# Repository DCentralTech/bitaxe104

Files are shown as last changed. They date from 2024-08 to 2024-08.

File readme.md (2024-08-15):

# The bitaxe
bitaxe is the first fully open source hardware Bitcoin ASIC miner.
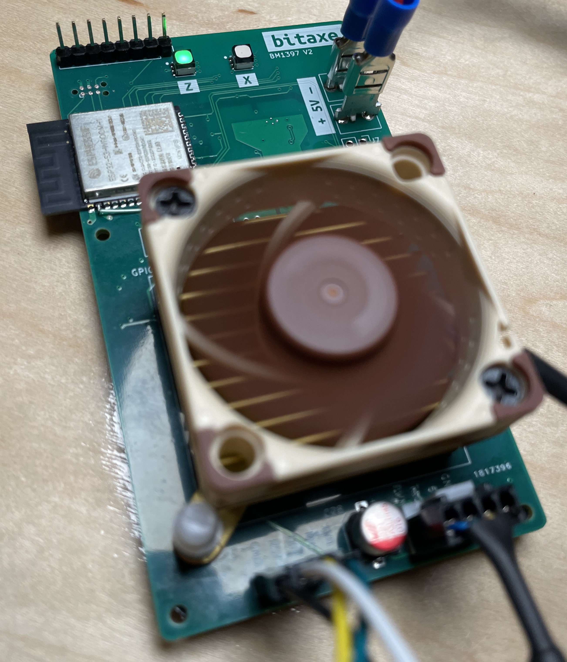
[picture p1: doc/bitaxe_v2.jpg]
bitaxeMax assembled


## Goals
- **Standalone**: can mine directly to your pool over WiFi. No External computer needed.
- **Embedded**: low cost, low maintenance, high availability, high reliability, low power.
- **ASIC**: based on the very efficient BM1397 from Bitmain.
- **Versatile**: solo/pool mining, autotune power/heat/efficiency.
- **Open Source**: All design files are provided.

## Features
- **ESP32-S3-WROOM-1** wifi microcontroller on board
- **TI TPS40305** buck regulator steps down the 5V input to power the BM1397
- **Maxim DS4432U+** current DAC digitally adjusts the BM1397 core voltage from 0.04V to 2.4V
- **TI INA260** power meter measures the input voltage and current of the miner
- **Microchip EMC2101** measures the BM1397 internal diode temperature. Also PWM controls the fan and monitors tach output.
- Two **sweet** RGB status LEDs

## BM1397
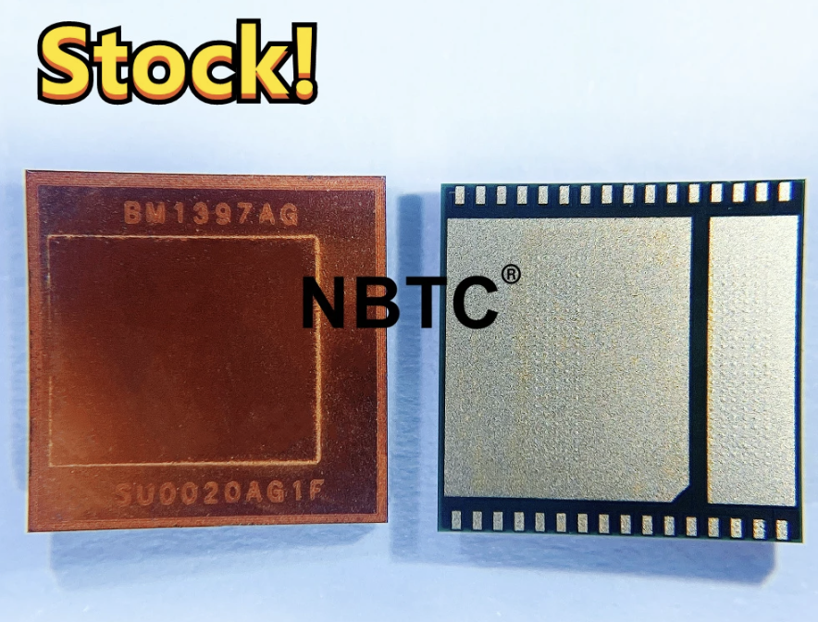
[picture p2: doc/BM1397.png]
BM1397 pic


- The BM1397 is a undocumented SHA256 mining ASIC from Bitmain. It's mostly used in the Antminer S17 and T17
- Bitmain claims the BM1397 has 0.03J/GH efficiency
- The BM1397 is available (new) for around $20 each and (used) for around $6 ea in small quantities.
- Choose your BM1397 version: [Guide here](https://d-central.tech/bm1397-ad-ag-ah-ai-antminer-17-series-chip-replacement-guide/)
- The BM1397 has the same footprint as the BM1387, but a very different pinout.
    - It also has two "Modes" that change some of the signal pins around to make chaining easy
- The BM1397 is driven by an undocumented protocol over UART. Baudrate is 115200bps by default but can go up to 6Mbps in order to provide mining jobs quickly enough to the ASIC daisy-chain.

## Current Status
- The hardware has been built and tested.
- Using cgminer on a separate computer, the bitaxe can mine in excess of 400 GH/s
- ESP32 miner firmware is still underdevelopment.

## Hardware
- [BM1397 from random AliExpress seller](https://www.aliexpress.com/item/3256802274958527.html). I got the "AG" variant. Not really sure what the difference is.
- [40x40mm heatsink and 5V fan](https://www.aliexpress.com/item/2251832861666365.html) from a random AliExpress seller. At least half of these arrived broken in some way. But they are cheap and the working ones do keep the BM1387's nice and cool when used with some thermal compound.
    - Swap this fan with the [Noctua NF-A4x10](https://noctua.at/en/products/fan/nf-a4x10-pwm) 5V 4-Pin fan for a much more pleasant experience.
- The BM1397 serial port is 1.8V. These pins are broken out, but the main idea is to communicate with the BM1397 from the ESP32
- Level shifters to interface the 1.8V BM1397 with the 3.3V ESP32. These pins are also broken out.
- [KiCad 6](https://www.kicad.org) design files
- All of the parts on the board are listed in the KiCad BOM

## Software
- [ESP-Miner](https://github.com/skot/ESP-Miner) firmware in progress.

## Power Supply Requirements
- [5VDC Power supply](https://www.amazon.com/BTF-LIGHTING-Plastic-Adapter-Transformer-WS2812B/dp/B01D8FM4N4). Should be capable of over 15W
    - Needs to connect with [spade-style connectors](https://www.amazon.com/gp/product/B01G4POUAU)

### ESP32 Programming Requirements
- [ESP-Prog](https://www.digikey.com/en/products/detail/espressif-systems/ESP-PROG/10259352) ESP32 Programmer
- [TC2030-IDC-NL](https://www.tag-connect.com/product/tc2030-idc-nl) Tag Connect Cable
- [TC2030-CLIP](https://www.tag-connect.com/product/tc2030-retaining-clip-board-3-pack)

## Connections
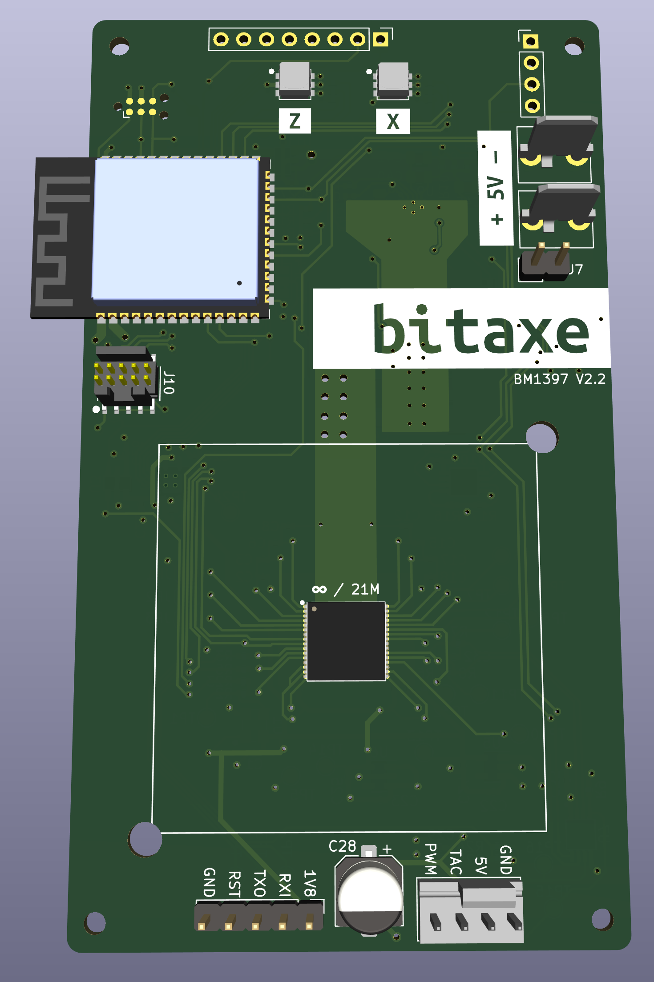
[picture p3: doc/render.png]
bitaxeMax KiCad render


### Power Input
| Pin Name | Description |
| --- | --- |
| +5V | Main input. This should be 5V, 15W |
| GND | Main input ground |

## Building
- Check out [building.md](building.md) for PCB ordering tips
- Check out [assembly.md](assembly.md) for assembly tips

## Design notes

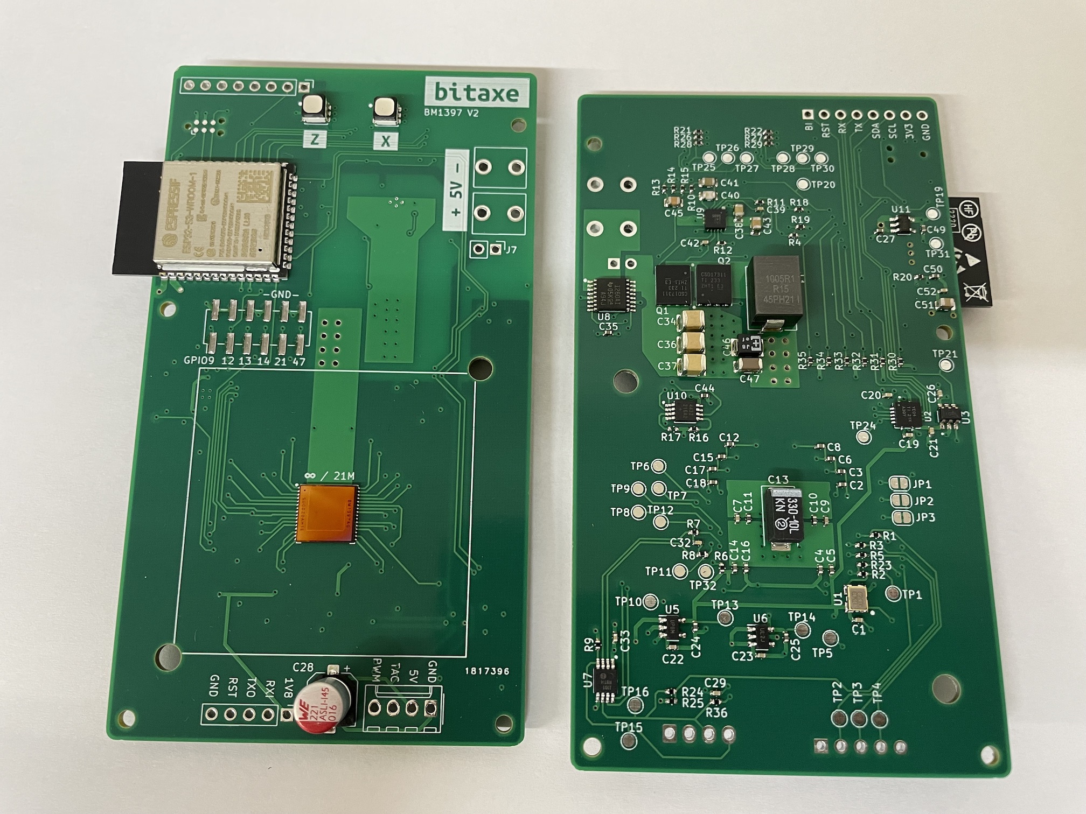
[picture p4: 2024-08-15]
doc/v2_both_sides.jpg

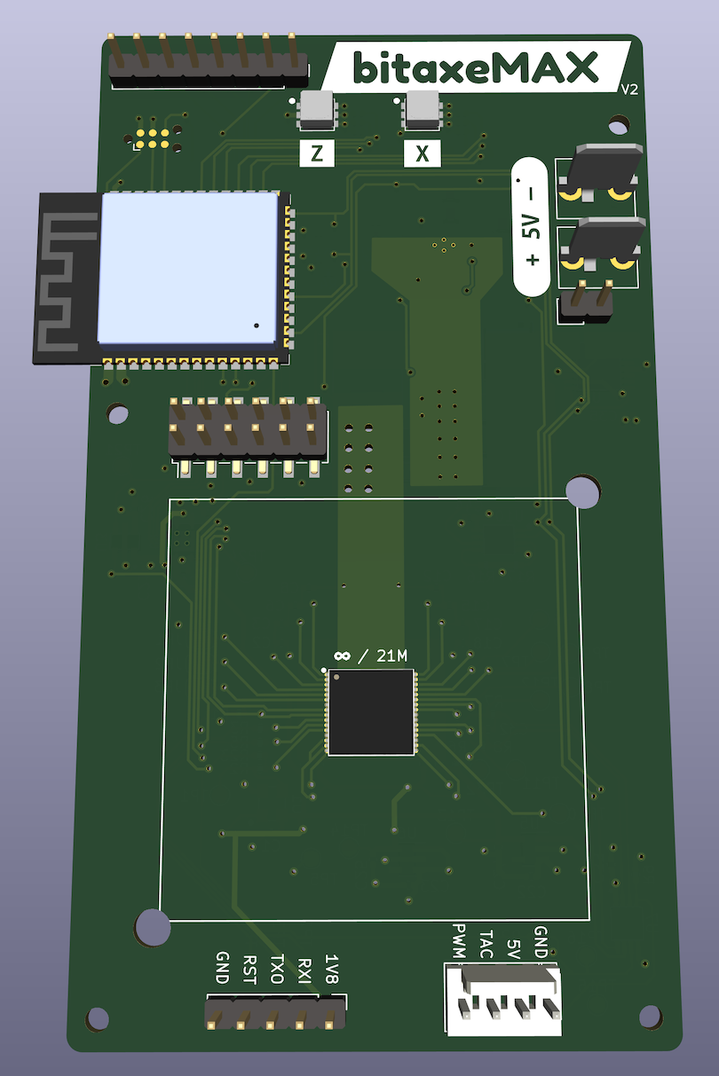
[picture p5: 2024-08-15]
doc/front.png

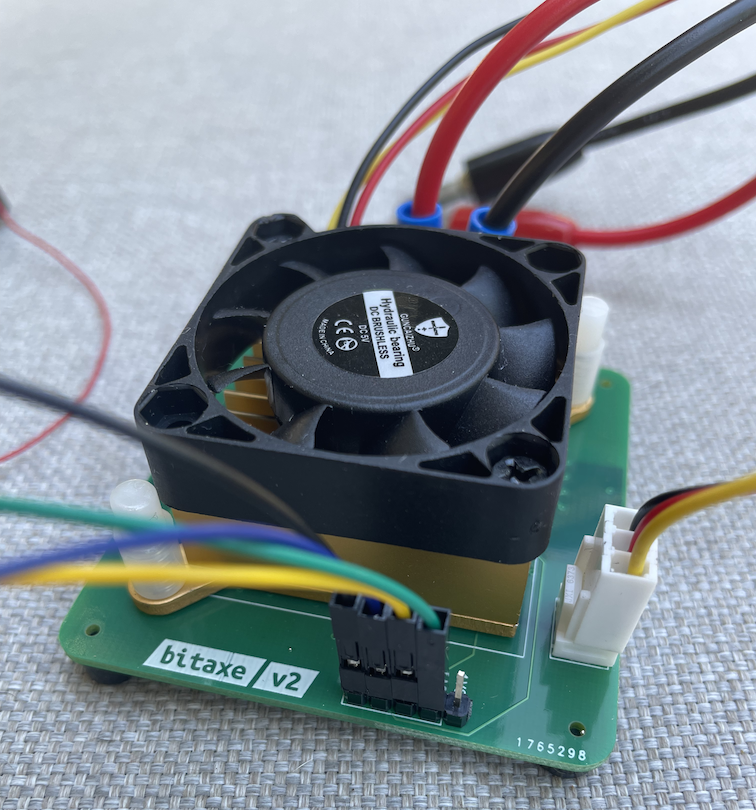
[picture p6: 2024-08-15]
doc/bitaxe.png

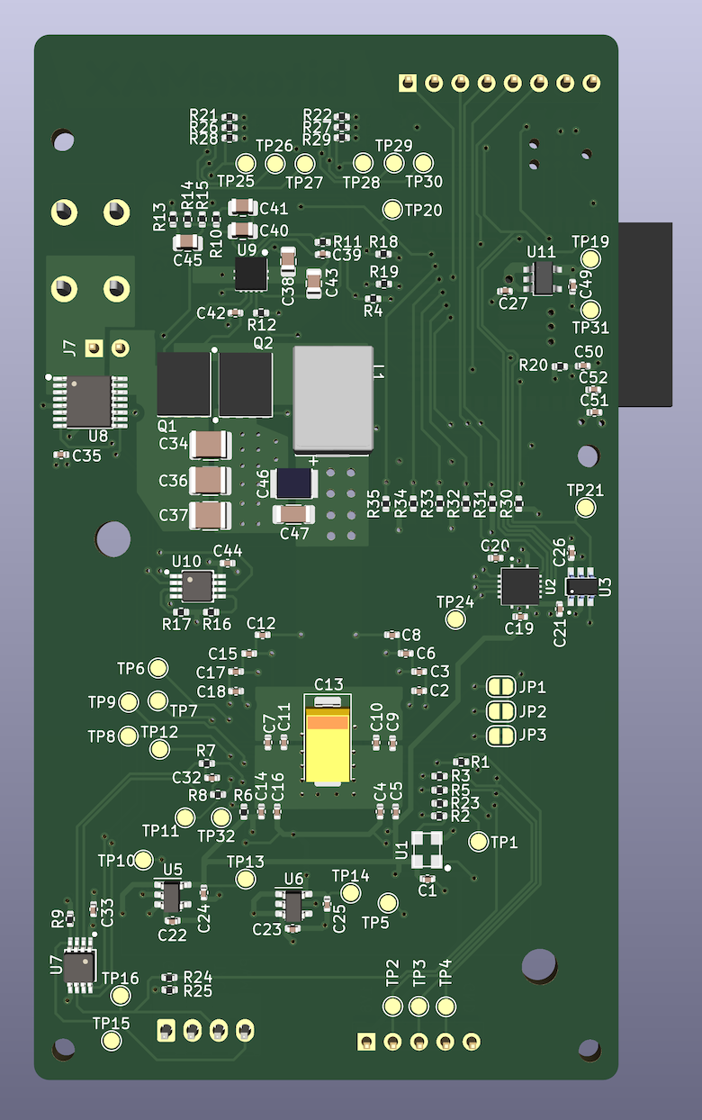
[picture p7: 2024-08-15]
doc/back.png

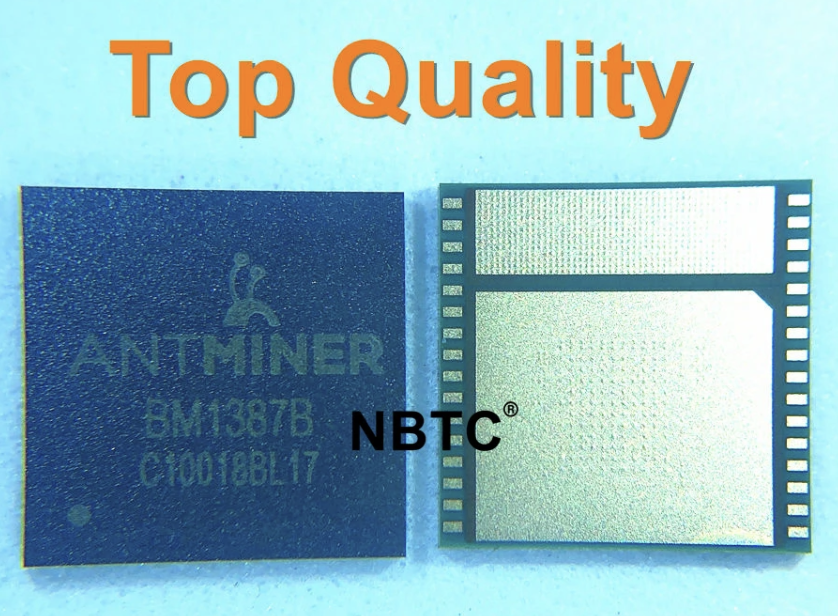
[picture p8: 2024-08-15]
doc/bm1387.png

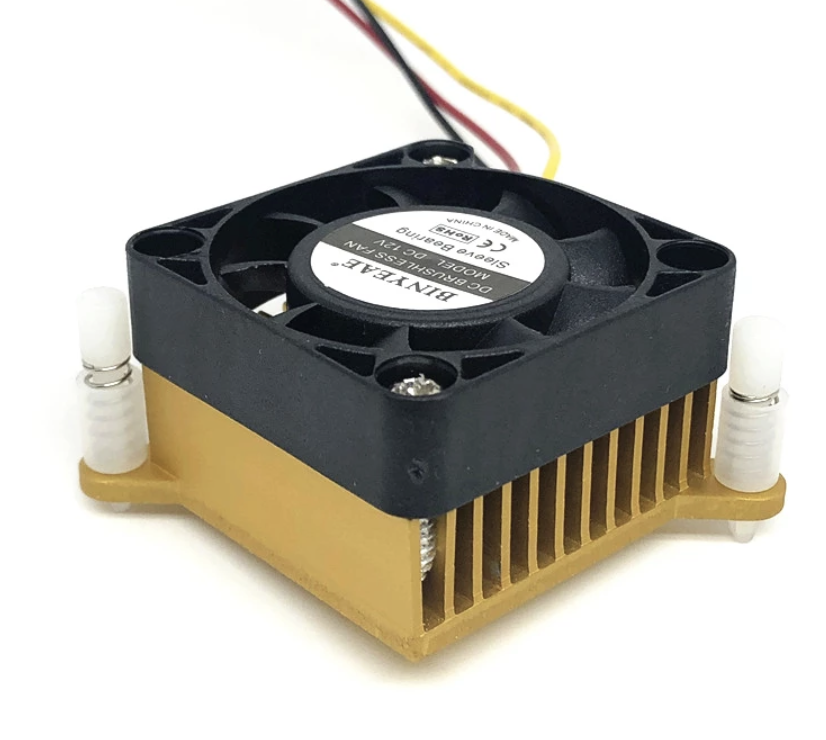
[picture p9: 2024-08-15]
doc/fan.png

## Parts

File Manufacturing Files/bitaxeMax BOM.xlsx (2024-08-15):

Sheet: BOM
Qty | Ref Des | Value | DK | PARTNO | DNP
13 | C1, C7, C9, C19, C20, C21, C22, C23, C26, C29, C33, C42, C52 | 0.1uF | 1292-1639-1-ND
21 | C2, C3, C4, C5, C6, C8, C10, C11, C12, C14, C15, C16, C17, C18, C24, C25, C27, C35, C44, C49, C50 | 1uF | 587-5514-1-ND
1 | C13 | 330uF | 718-1028-1-ND
1 | C28 | 220uF | 732-8422-1-ND | 865080345012
2 | C30, C31 | 6.8pF | 399-C0402C689C5GAC7867CT-ND | C0402C689C5GAC7867
1 | C32 | 470pF | 1276-1566-1-ND
3 | C34, C36, C37 | 47uF | 490-6539-1-ND | GRM32ER61C476KE15L
1 | C38 | 1uF | 1276-6471-1-ND
1 | C39 | 3.3nF | 1276-1552-1-ND
1 | C40 | 180pF | 311-1114-1-ND
1 | C41 | 1.5nF | 311-1128-1-ND
2 | C43, C51 | 10uF | 1276-1096-1-ND
1 | C45 | 470pF | 1292-1580-1-ND
1 | C46 | 220uF | P16200CT-ND | 2R5TPE220MAFB
1 | C47 | 100uF | 445-6008-1-ND | C3216X5R0J107M160AB
4 | H1, H2, H3, H4 | AlignmentHole |  | https://www.amazon.com/dp/B07MDFS1YS | T
2 | H5, H6 | MountingHole |  |  | T
1 | IC1 | BM1397_mode1 |  |  | T
2 | J1, J2 | Conn_01x01 | A100886CT-ND | 63862-1
1 | J3 | Conn_01x05 |  |  | T
1 | J4 | Conn_01x04 | WM4330-ND | 0470531000
1 | J5 | TC2030-IDC |  |  | T
1 | J6 | Conn_01x08 |  |  | T
1 | J7 | Conn_01x02 |  |  | T
1 | J9 | Conn_01x04 |  |  | T
1 | J10 | FTSH-105-01-F-DV-K | SAM8796-ND
2 | JP1, JP2 | SolderJumper_2_Open |  |  | T
1 | JP3 | SolderJumper_2_Bridged |  |  | T
1 | JP4 | JTAG Source
1 | L1 | 150nH | 513-1568-1-ND | FP1005R1-R15-R
2 | Q1, Q2 | CSD17311Q5 | 296-27625-1-ND | CSD17311Q5
3 | R1, R18, R19 | 1k | YAG2306CT-ND |  | T
4 | R2, R3, R5, R23 | 0 | RMCF0402ZT0R00CT-ND
6 | R4, R6, R9, R20, R24, R36 | 10k | 311-10KJRCT-ND
2 | R7, R8 | 100 | RMCF0402FT100RCT-ND
1 | R10 | 3.83k | 311-3.83KLRCT-ND
1 | R11 | 100k | 311-100KJRCT-ND
1 | R12 | 4.12k | RMCF0402FT4K12CT-ND
1 | R13 | 1.33k | 311-1.33KLRCT-ND
1 | R14 | 4.99k | 311-4.99KLRCT-ND
1 | R15 | 3.32k | 311-3.32KLRCT-ND
1 | R16 | 80k | 311-80.6KLRCT-ND
1 | R17 | DNP |  |  | T
2 | R21, R22 | 60.4 | 311-60.4LRCT-ND
1 | R25 | 19.1k | YAG3027CT-ND
2 | R26, R27 | 100 | RMCF0402FT100RCT-ND
2 | R28, R29 | 261 | YAG3078CT-ND
31 | TP1, TP2, TP3, TP4, TP5, TP6, TP7, TP8, TP9, TP10, TP11, TP12, TP13, TP14, TP15, TP16, TP17, TP18, TP19, TP21, TP22, TP23, TP24, TP25, TP26, TP27, TP28, TP29, TP30, TP31, TP32 | TestPoint |  |  | T
1 | U1 | 25MHz | 1908-O250-JO32-B-1V3-1-T1-LFCT-ND | O 25,0-JO32-B-1V3-1-T1-LF
1 | U2 | TXB0104RGYR | 296-21930-1-ND | TXB0104RGYR
1 | U3 | SN74AXC1T45DBVR | 296-47598-1-ND | SN74AXC1T45DBVR
2 | U4, U13 | CLX6E-FKC | CLX6E-FKC-CH1M1D1BB7C3D3CT-ND | CLX6E-FKC-CH1M1D1BB7C3D3
1 | U5 | MCP1824 | MCP1824T-1802E/OTCT-ND | MCP1824T-1802E/OT
1 | U6 | MCP1824 | MCP1824T-0802E/OTCT-ND | MCP1824T-0802E/OT
1 | U7 | EMC2101 | EMC2101-R-ACZL-CT-ND | EMC2101-R-ACZL-TR
1 | U8 | INA260 | 296-47777-1-ND | INA260AIPWR
1 | U9 | TPS40305 | 296-37445-1-ND | TPS40305DRCR
1 | U10 | DS4432U+ | DS4432U+-ND | DS4432U+
1 | U11 | RT9080-33GJ5 | 1028-1509-1-ND | RT9080-33GJ5
1 | U12 | ESP32-S3-WROOM-1 | 1965-ESP32-S3-WROOM-1-N16R8CT-ND | ESP32-S3-WROOM-1-N16R8
1 | Y1 | 32.768kHz | 728-1074-1-ND | SC32S-7PF20PPM

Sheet: DK Order
Qty | Ref Des | DK
13 | C1, C7, C9, C19, C20, C21, C22, C23, C26, C29, C33, C42, C52 | 1292-1639-1-ND
21 | C2, C3, C4, C5, C6, C8, C10, C11, C12, C14, C15, C16, C17, C18, C24, C25, C27, C35, C44, C49, C50 | 587-5514-1-ND
1 | C13 | 718-1028-1-ND
1 | C28 | 732-8422-1-ND
2 | C30, C31 | 399-C0402C689C5GAC7867CT-ND
1 | C32 | 1276-1566-1-ND
3 | C34, C36, C37 | 490-6539-1-ND
1 | C38 | 1276-6471-1-ND
1 | C39 | 1276-1552-1-ND
1 | C40 | 311-1114-1-ND
1 | C41 | 311-1128-1-ND
2 | C43, C51 | 1276-1096-1-ND
1 | C45 | 1292-1580-1-ND
1 | C46 | P16200CT-ND
1 | C47 | 445-6008-1-ND
2 | J1, J2 | A100886CT-ND
1 | J4 | WM4330-ND
1 | J10 | SAM8796-ND
1 | JP4
1 | L1 | 513-1568-1-ND
2 | Q1, Q2 | 296-27625-1-ND
4 | R2, R3, R5, R23 | RMCF0402ZT0R00CT-ND
6 | R4, R6, R9, R20, R24, R36 | 311-10KJRCT-ND
2 | R7, R8 | RMCF0402FT100RCT-ND
1 | R10 | 311-3.83KLRCT-ND
1 | R11 | 311-100KJRCT-ND
1 | R12 | RMCF0402FT4K12CT-ND
1 | R13 | 311-1.33KLRCT-ND
1 | R14 | 311-4.99KLRCT-ND
1 | R15 | 311-3.32KLRCT-ND
1 | R16 | 311-80.6KLRCT-ND
2 | R21, R22 | 311-60.4LRCT-ND
1 | R25 | YAG3027CT-ND
2 | R26, R27 | RMCF0402FT100RCT-ND
2 | R28, R29 | YAG3078CT-ND
1 | U1 | 1908-O250-JO32-B-1V3-1-T1-LFCT-ND
1 | U2 | 296-21930-1-ND
1 | U3 | 296-47598-1-ND
2 | U4, U13 | CLX6E-FKC-CH1M1D1BB7C3D3CT-ND
1 | U5 | MCP1824T-1802E/OTCT-ND
1 | U6 | MCP1824T-0802E/OTCT-ND
1 | U7 | EMC2101-R-ACZL-CT-ND
1 | U8 | 296-47777-1-ND
1 | U9 | 296-37445-1-ND
1 | U10 | DS4432U+-ND
1 | U11 | 1028-1509-1-ND
1 | U12 | 1965-ESP32-S3-WROOM-1-N16R8CT-ND
1 | Y1 | 728-1074-1-ND

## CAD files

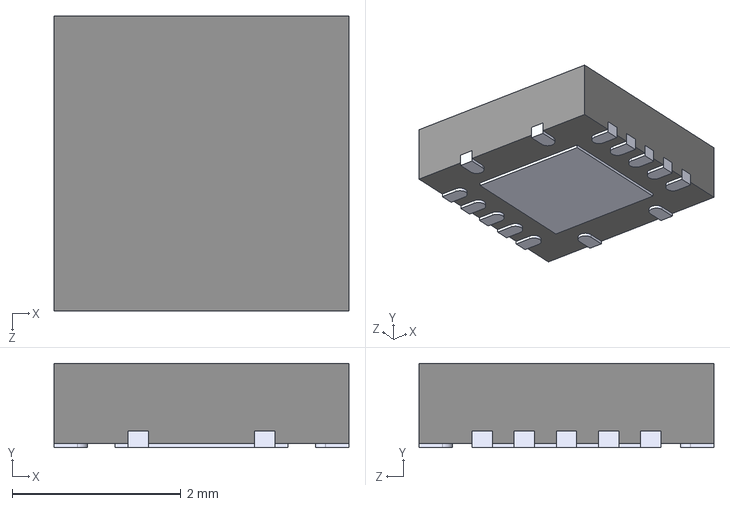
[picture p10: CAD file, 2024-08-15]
3d/TXB0104RGYR.STEP
3.50 x 1.00 x 3.50 mm

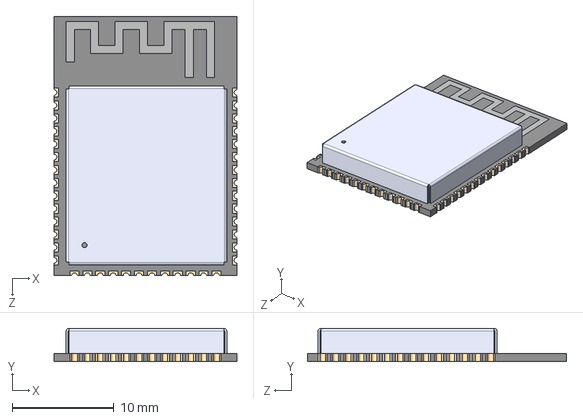
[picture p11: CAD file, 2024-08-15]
3d/ESP32-S3-WROOM-1-N8R2--3DModel-STEP-56544.STEP
18.0 x 3.25 x 25.5 mm

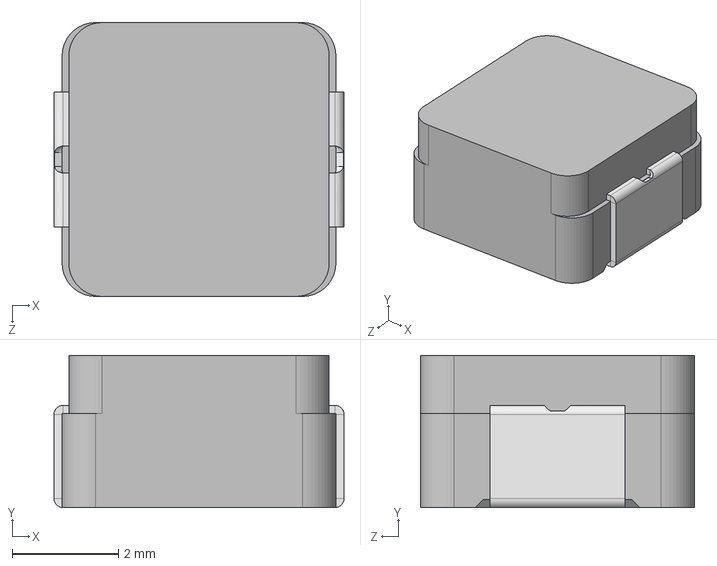
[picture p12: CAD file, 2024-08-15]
3d/IHLP2020CZ.step
5.45 x 2.86 x 5.15 mm

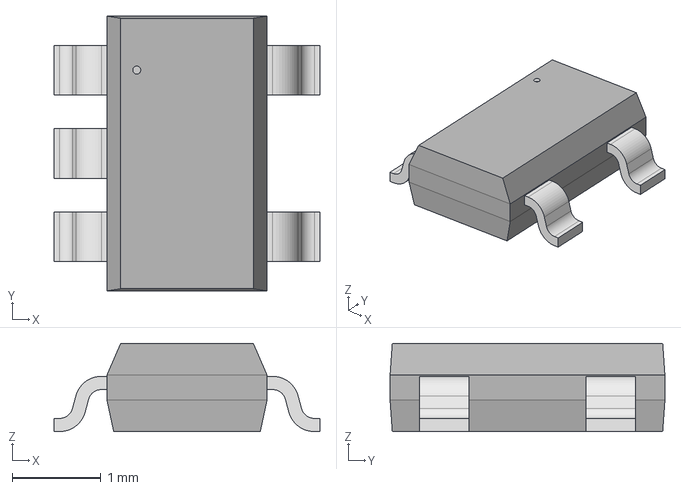
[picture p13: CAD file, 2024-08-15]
3d/TSOT-23-5_RIT.step
3.00 x 3.10 x 0.993 mm

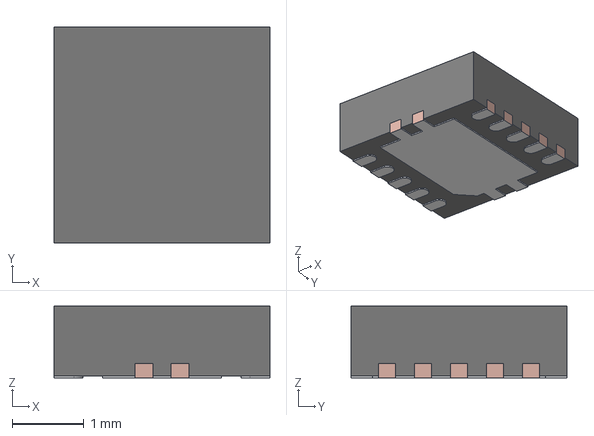
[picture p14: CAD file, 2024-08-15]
3d/DRC0010J.stp
3.00 x 3.00 x 1.00 mm
BODY-SON
FRAME-DRC0010J

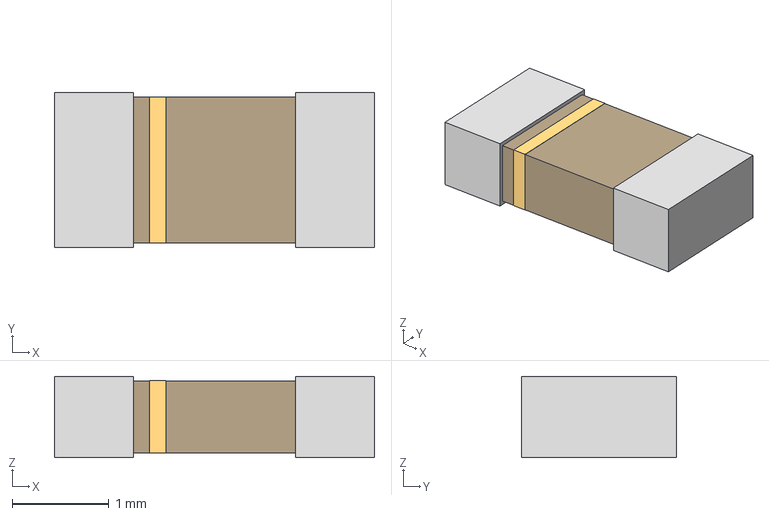
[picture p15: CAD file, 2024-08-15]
3d/XTAL_SC32S-7PF20PPM_EPS.step
3.30 x 1.60 x 0.838 mm

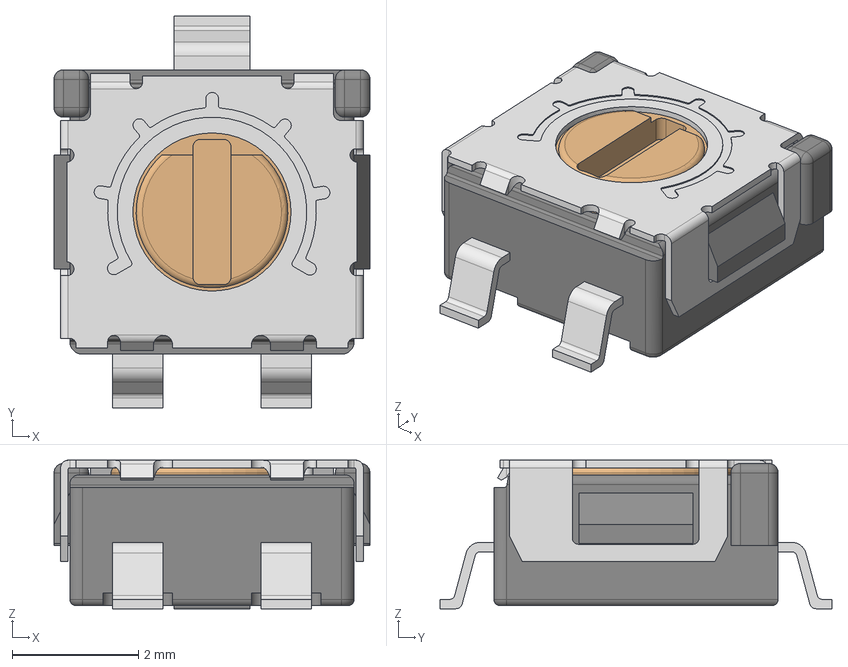
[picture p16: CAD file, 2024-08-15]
3d/ST-4ETB2k_(202).stp
5.00 x 6.20 x 2.35 mm
ST-4EB_terminal_2
ST-4EB_terminal
ST-4EB_terminal_1
ST-4-dial2
ST-4EB10X(100)_body

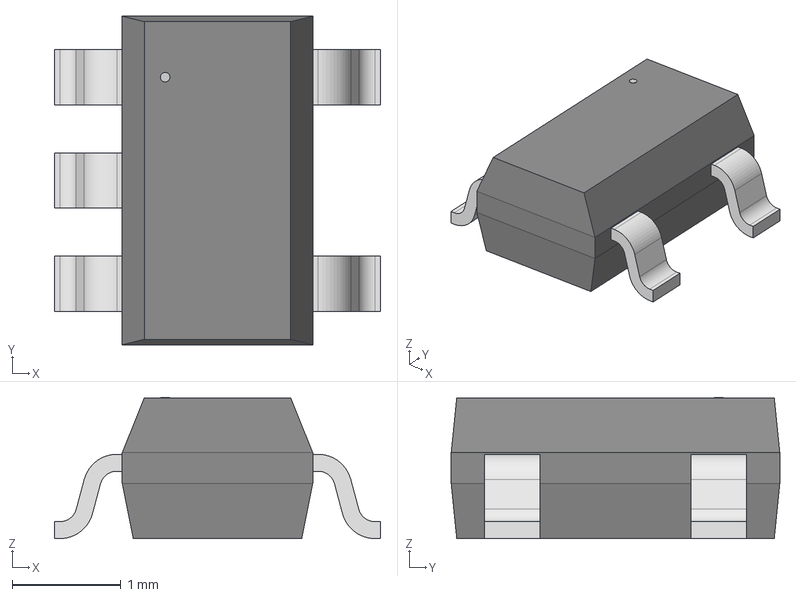
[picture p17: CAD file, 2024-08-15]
3d/SOT-23-5_M5_MCH.step
3.00 x 3.02 x 1.30 mm

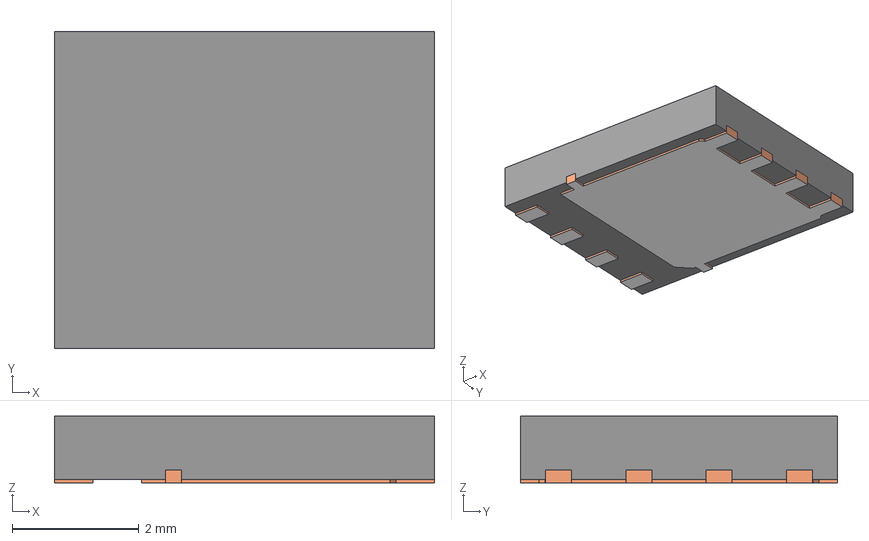
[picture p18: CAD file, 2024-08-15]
3d/DQH0008A.stp
6.00 x 5.00 x 1.05 mm
BODY-SON
FRAME-DQH0008A
PIN1-ID

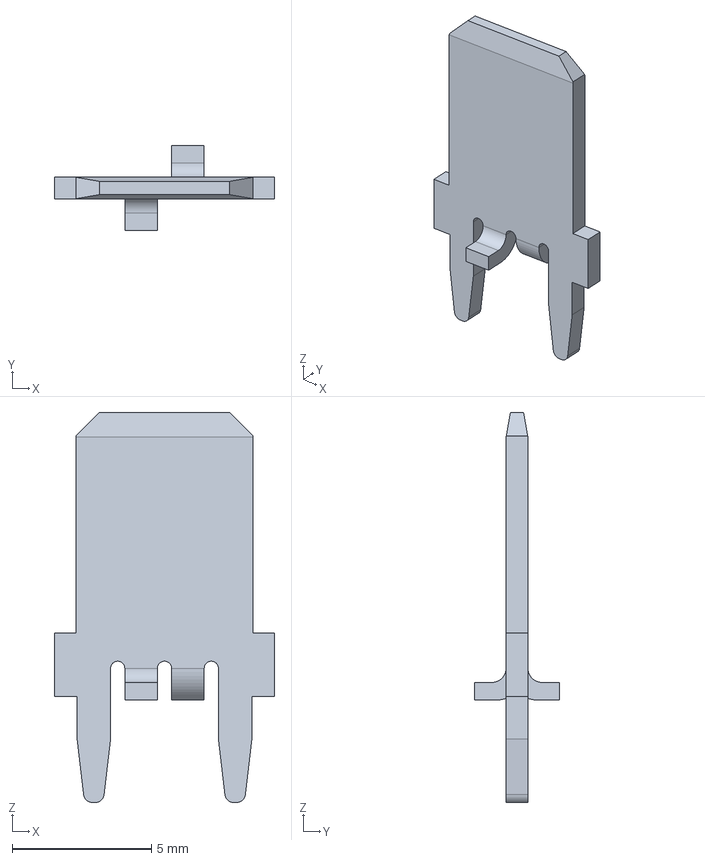
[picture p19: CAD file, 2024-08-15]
3d/c-63862-1-r-3d.stp
7.92 x 3.07 x 14.0 mm

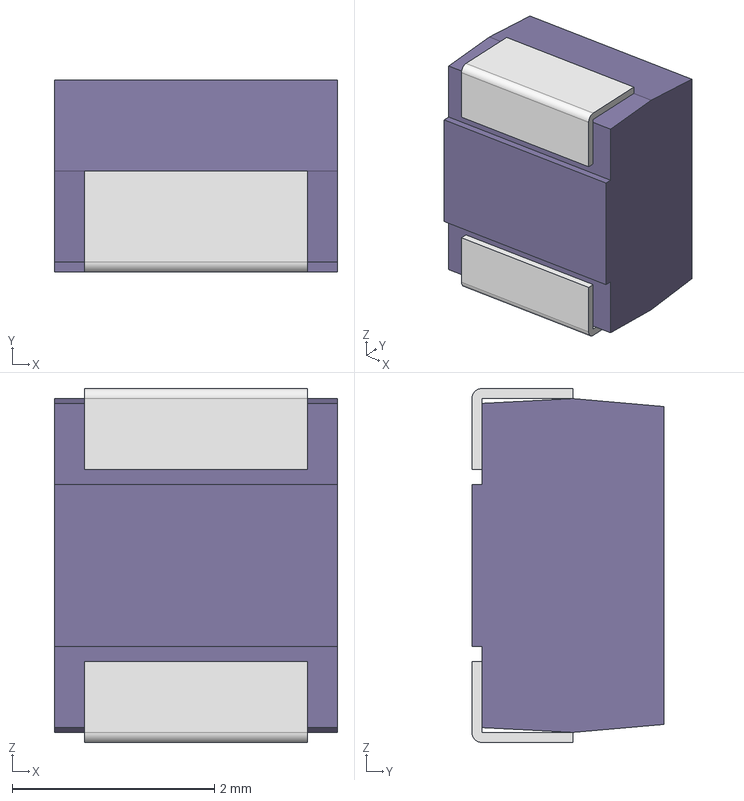
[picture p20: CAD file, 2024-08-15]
3d/2R5TPE220MAFB.step
2.80 x 1.90 x 3.50 mm
mold-B2
flame-B2 x 2

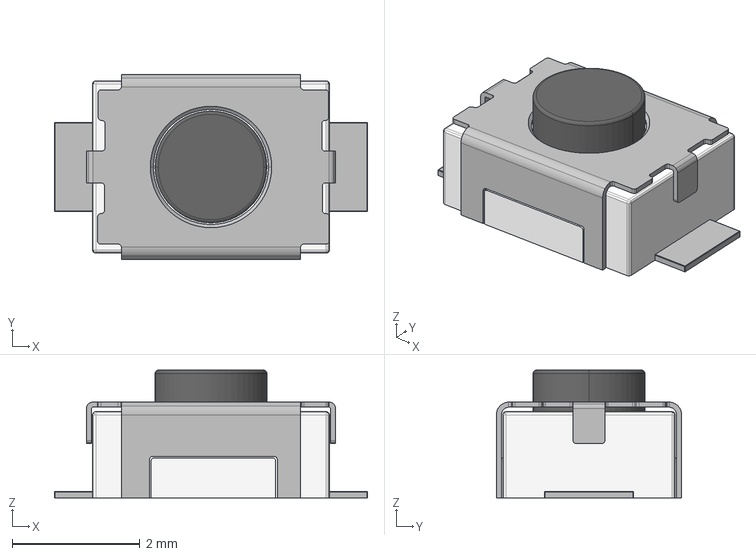
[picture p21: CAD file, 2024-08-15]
3d/CS1213AG-tr.stp
4.90 x 2.90 x 2.00 mm

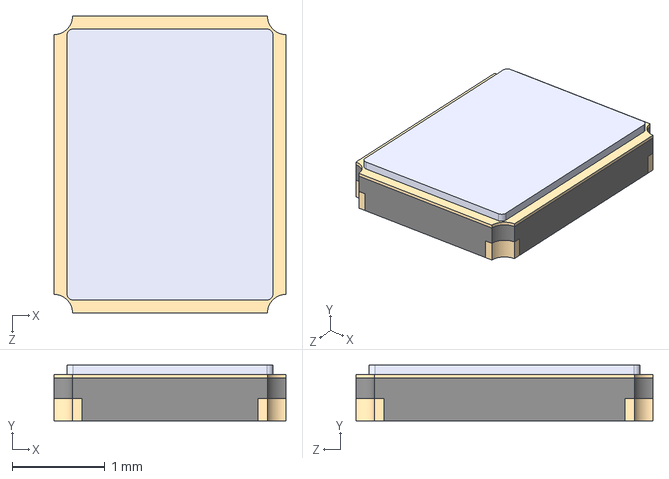
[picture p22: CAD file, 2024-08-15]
3d/CX3225SB16000H0FLJCC.STEP
2.50 x 0.6 x 3.20 mm

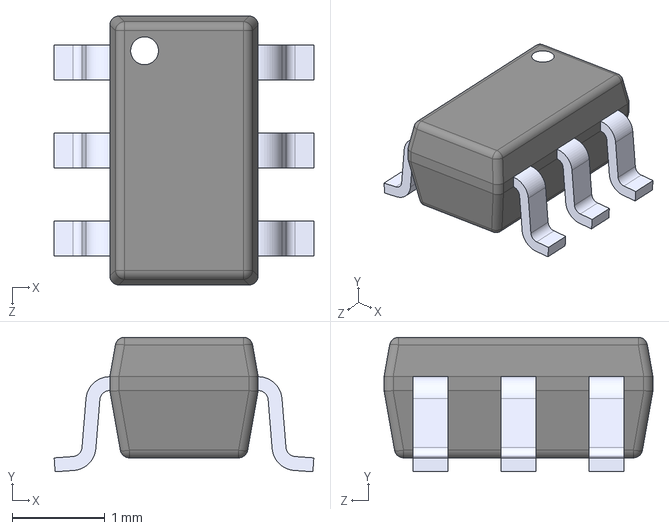
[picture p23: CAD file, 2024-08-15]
3d/SN74AXC1T45DBVR.STEP
2.80 x 1.45 x 2.90 mm

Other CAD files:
3d/Cree_PLCC6.stp
3d/FP1006V2-R.STEP
3d/21-0164B_L622-1_MXM.step
3d/54-00164.STEP
3d/470531000.stp
3d/DQG0008A.stp
3d/DRL0006A.stp
3d/FTSH-105-01-F-DV-K.stp
3d/PLCC6_LED_3_5X3_4X2_8_CRW.step
3d/SMV_z90.stp
3d/SW_CS1213AGF260_CRS.step
3d/XRCGB27M120F3M10R0_MUR.step

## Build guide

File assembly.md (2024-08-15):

- Get a convection toaster oven. Nothing fancy, it just has a fan inside for more even heating. This is like a $50 Black and Decker kind of thing. Never use this oven for food.
- Get a thermocouple thermometer. These are $30ish
- Use Sn63/Pb37 no-clean, leaded, solder paste. I usually get MG Chemicals brand, in a syringe. Keep it in the refrigerator so it's nice and cold before you stencil it. (obvs don't get it near your food). Wash your hands well after.
- Take your time to get the paste stenciled right. Don't be afraid to wipe it off with IPA and try again. The paste stencils better when it's cold.
- Use tweezers to put all of the parts on the pasted board.
- Put the board(s) in the toaster oven. I usually put them right on the wire rack, which is in the metal tray.
- Put the thermocouple inside the toaster oven. Close the door on the thermocouple wire so that it holds the end right above the PCB, inside the oven.
- Turn the oven on bake, medium setting.
- Once the temp gets to 140C, turn down the oven heat and try and keep it at 140-150C for 2 minutes. Open the door a little if it's getting to hot. This is the "Soak" phase
- After two minutes, turn the heat to high
- Once the temp reaches 200C start a timer for 30 seconds. Keep the temp between 200 and 220C for this phase. Usually you don't need to do anything. This is the "Reflow" phase. You should see all of the paste melt.
- After 30 seconds, turn off the toaster oven. open the door.
- Let the boards cool for a bit in the oven with the door open.
- Once cool to touch, inspect the boards with a microscope for dry pads and/or bridges. Depending on how well you did with stenciling there may be a few, especially on QFP packages. QFNs sometimes too. Fix these up with paste flux, solder braid and your soldering iron.

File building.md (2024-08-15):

# Building PCBs

In order to get PCBs made, you usually need to provide them with the following files;

- Gerbers
- Drill Files

Additionally if you want to have a shop assemble the boards for you, you’ll also need to provide;

- Bill of Materials (BOM)
- Centroid file (XY)

### Generating Gerbers and Drill Files

Gerbers are a set of files in a standard format that allow a PCB manufacturer to build the PCB. Usually there is one gerber file for each layer of a PCB. A Gerber file can represent a wide variety of different layer types;

- Copper layer
- Silkscreen Layer
- Soldermask layer
- Board outline
- Drills (Okay, this is actually not a gerber, but your PCB house will definitely need it)

Any* PCB CAD software will allow you to generate gerbers. We use [KiCad](https://www.kicad.org) because it is open source, free, and *awesome*. Here is how to generate gerbers in KiCad v6;

1. Open up the design in KiCad and switch to the PCB board editor view (ie not the schematic). Some people call this pcbnew.
2. Choose File → Fabrication Outputs → Gerbers (.gbr)…
3. Pick the right options for what your PCB board house expects. Here is what I use;

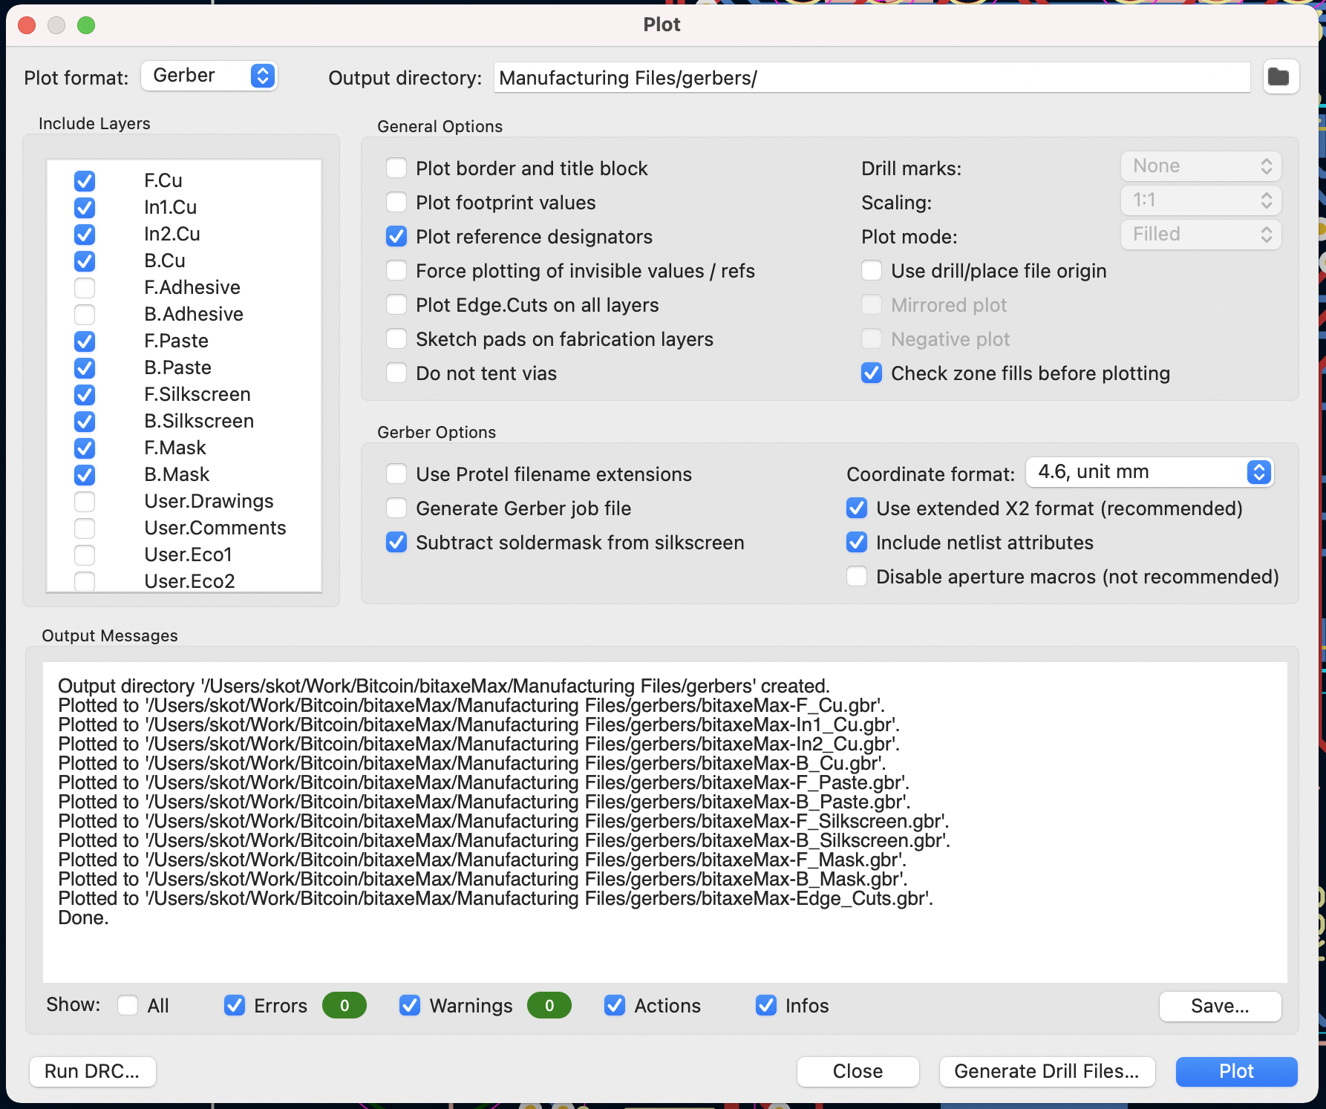
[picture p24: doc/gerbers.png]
Gerber Plot Window


Make sure you have these “Include Layers” checked;

- **F.Cu** → Front copper
- **In1.Cu** → Inner layer 1 Copper
- **In2.Cu** → Inner layer 2 Copper
- **B.Cu** → Back copper
- **F.Paste** → Front Paste. Note: this is used to make a solder paste stencil. This is optional. Many PCB houses will let you order stencils as a separate step. use these gerbers for ordering a stencil
- **B.Paste** → Back paste. see note above
- **F.Silkscreen** → Front Silkscreen. sometimes this is called the Legend
- **B.Silkscreen** → Back Silkscreen. sometimes this is called the Legend of Zelda
- **F.Mask** → Front soldermask
- **B.Mask** → Back soldermask
- **Edge.Cuts** → The board outline. This defines the shape the PCB is cut to.

1. Next you’ll want to generate the drill files. Click that button in the lower right corner of the “Plot” screen from above.
2. Generate the drill files according to your PCB house specs. Here are the options I use;

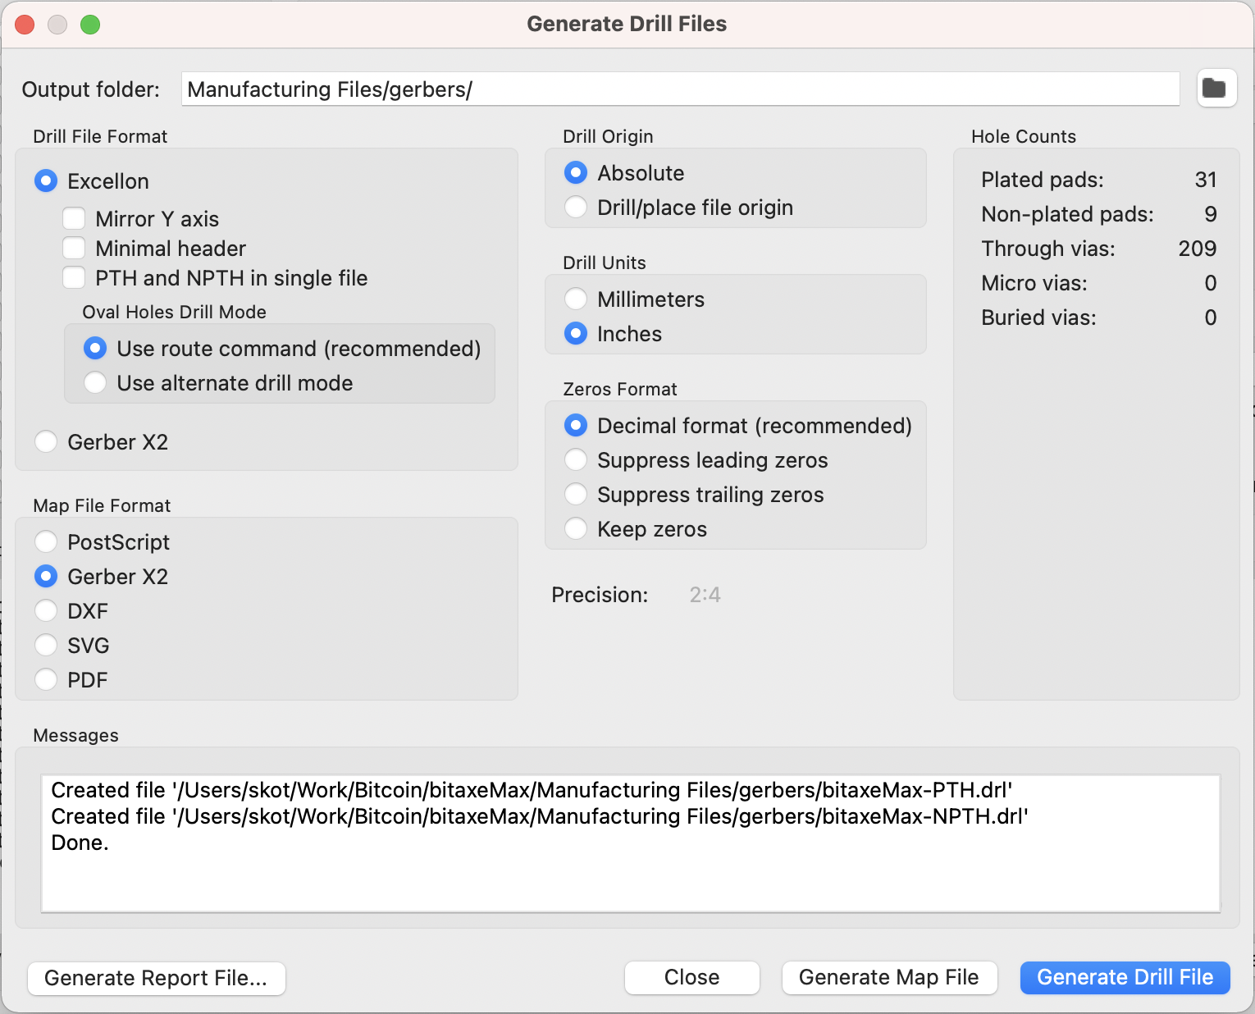
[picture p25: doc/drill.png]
Drill Files Window


That’s it! Take all of those generated files and give them to your PCB house. If you’re ordering stencils (which you should!), pull out `-F_Paste.gbr` and `-B_Paste.gbr` and send those to the right place. Paste gerbers are not needed to manufacture a PCB.

### Generating PCBA Manufacturing files

- TBD

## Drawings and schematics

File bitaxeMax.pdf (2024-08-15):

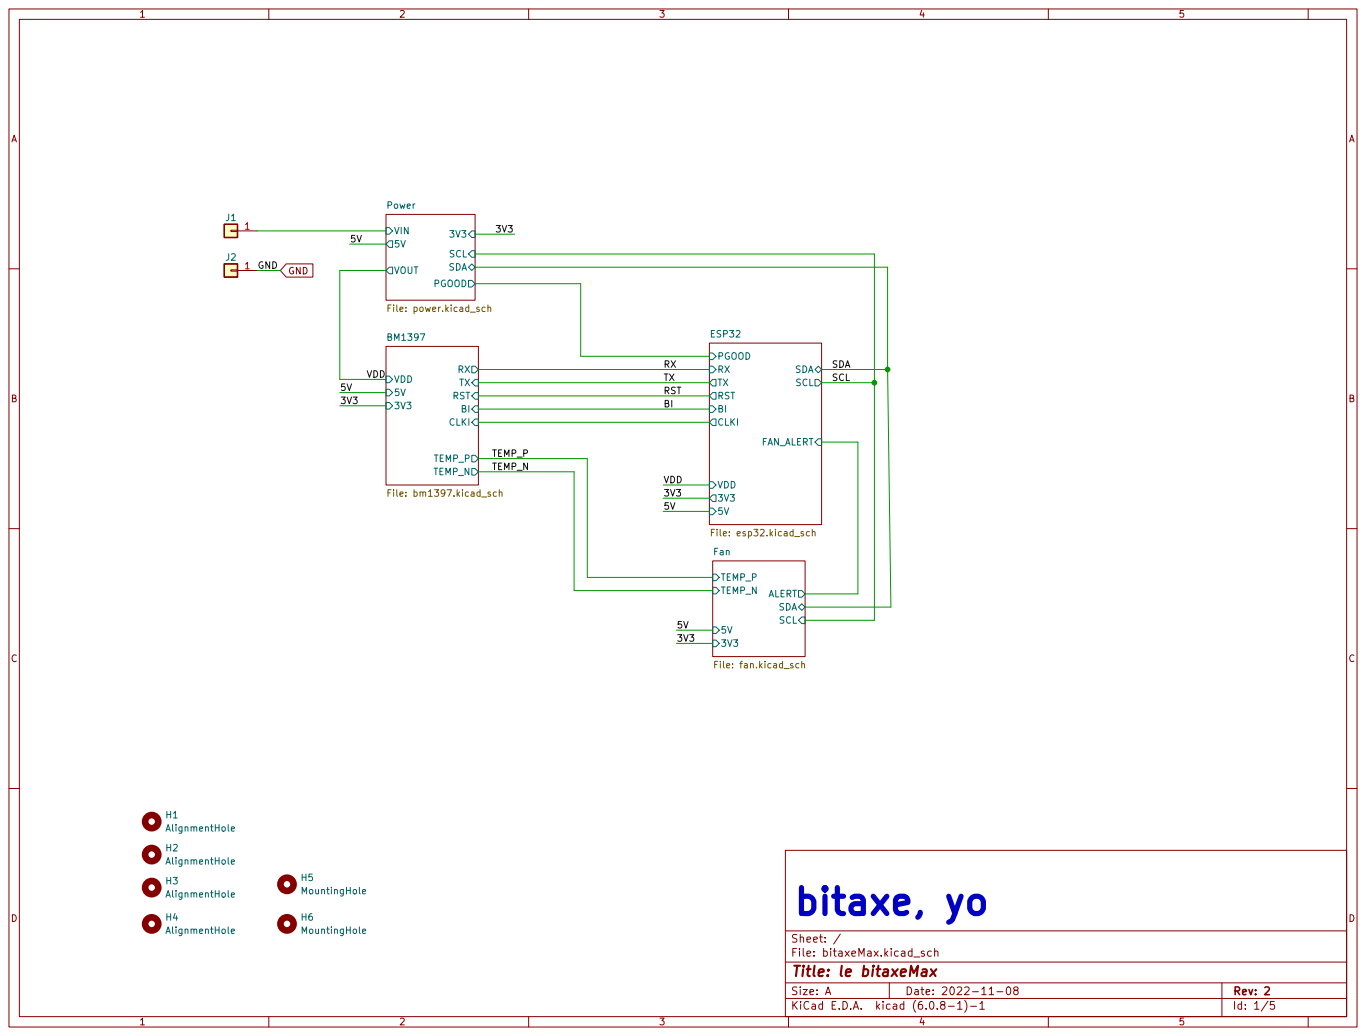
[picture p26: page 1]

BI CLKI BM1397 File: bm1397.kicad_sch VOUT VIN

File: bitaxeMax.kicad_sch Sheet: /
Id: 1/5 Title: le bitaxeMax

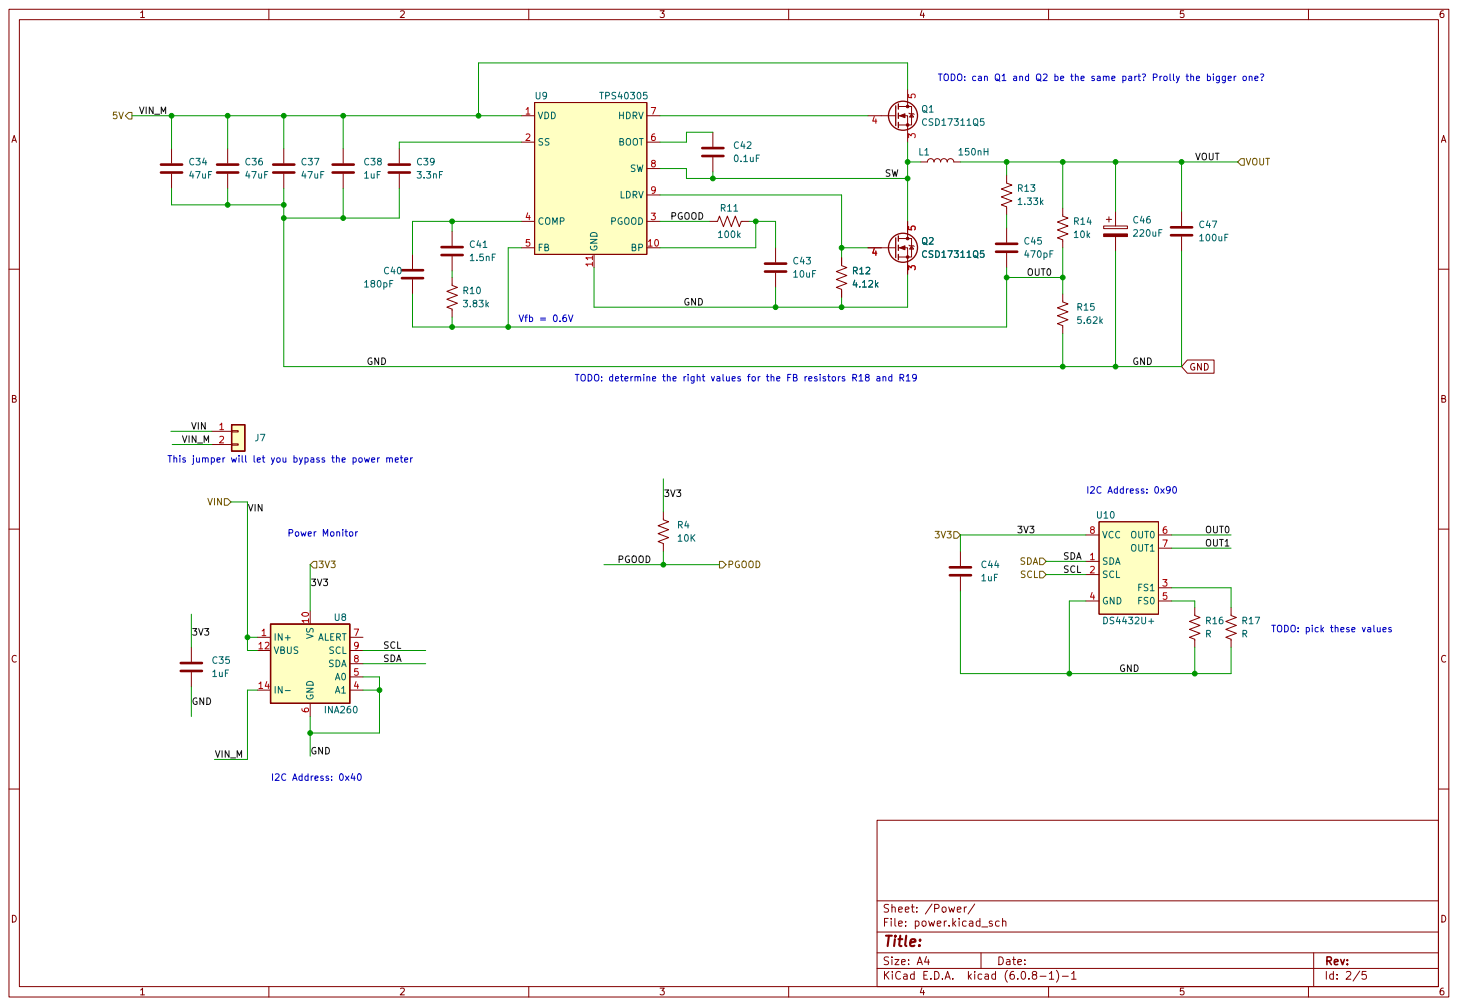
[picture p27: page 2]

TODO: can Q1 and Q2 be the same part? Prolly the bigger one?

TODO: determine the right values for the FB resistors R18 and R19 R12

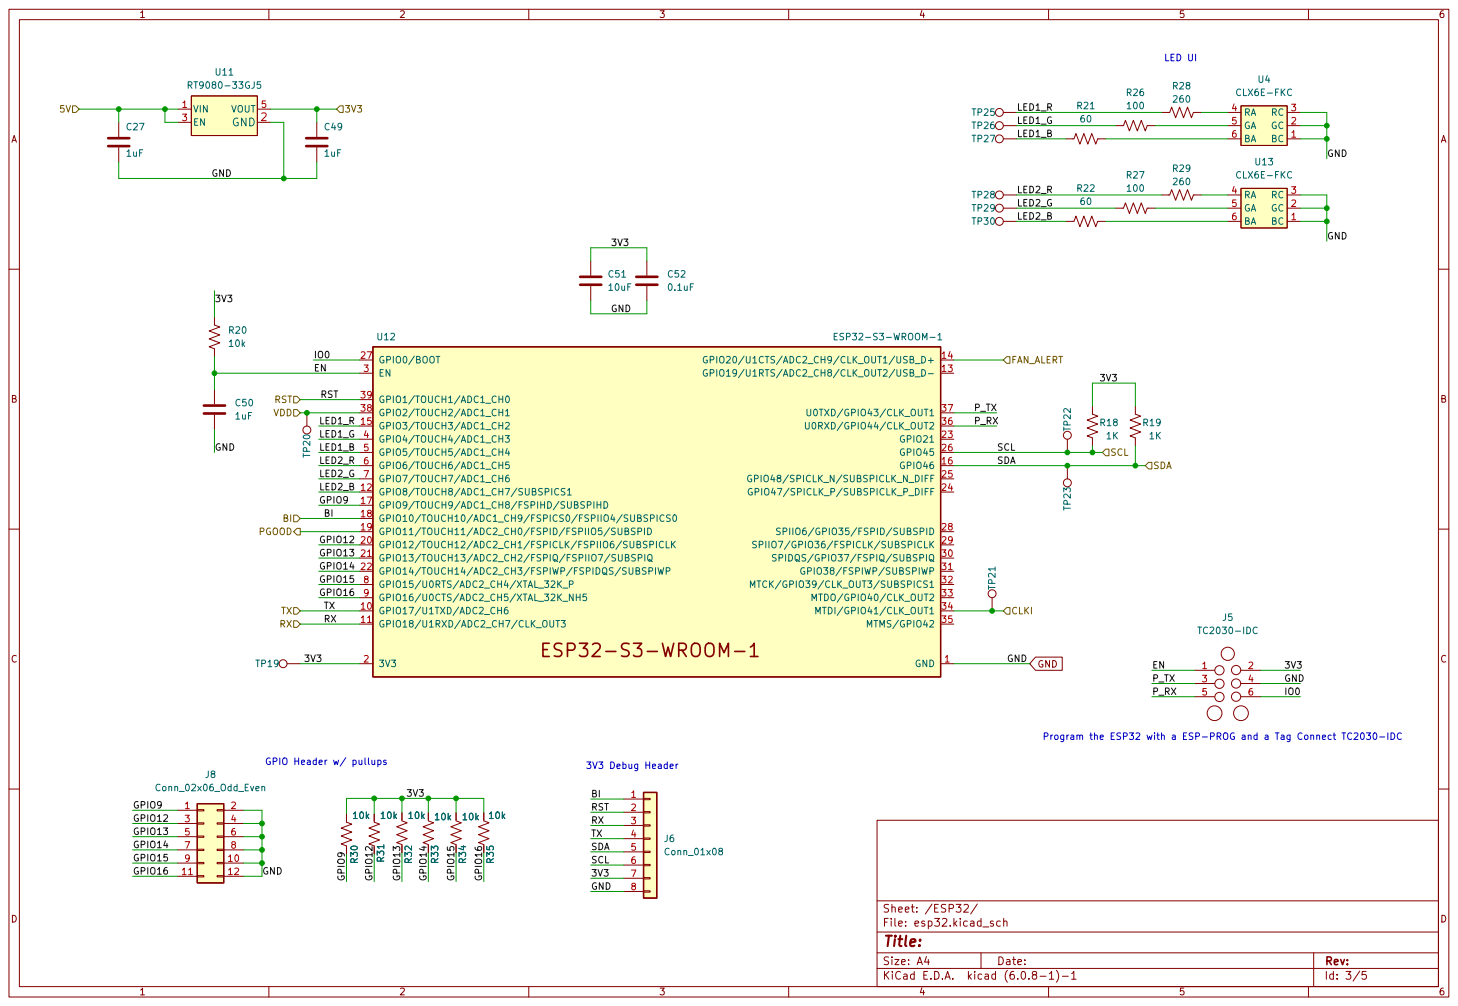
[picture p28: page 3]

Program the ESP32 with a ESP-PROG and a Tag Connect TC2030-IDC

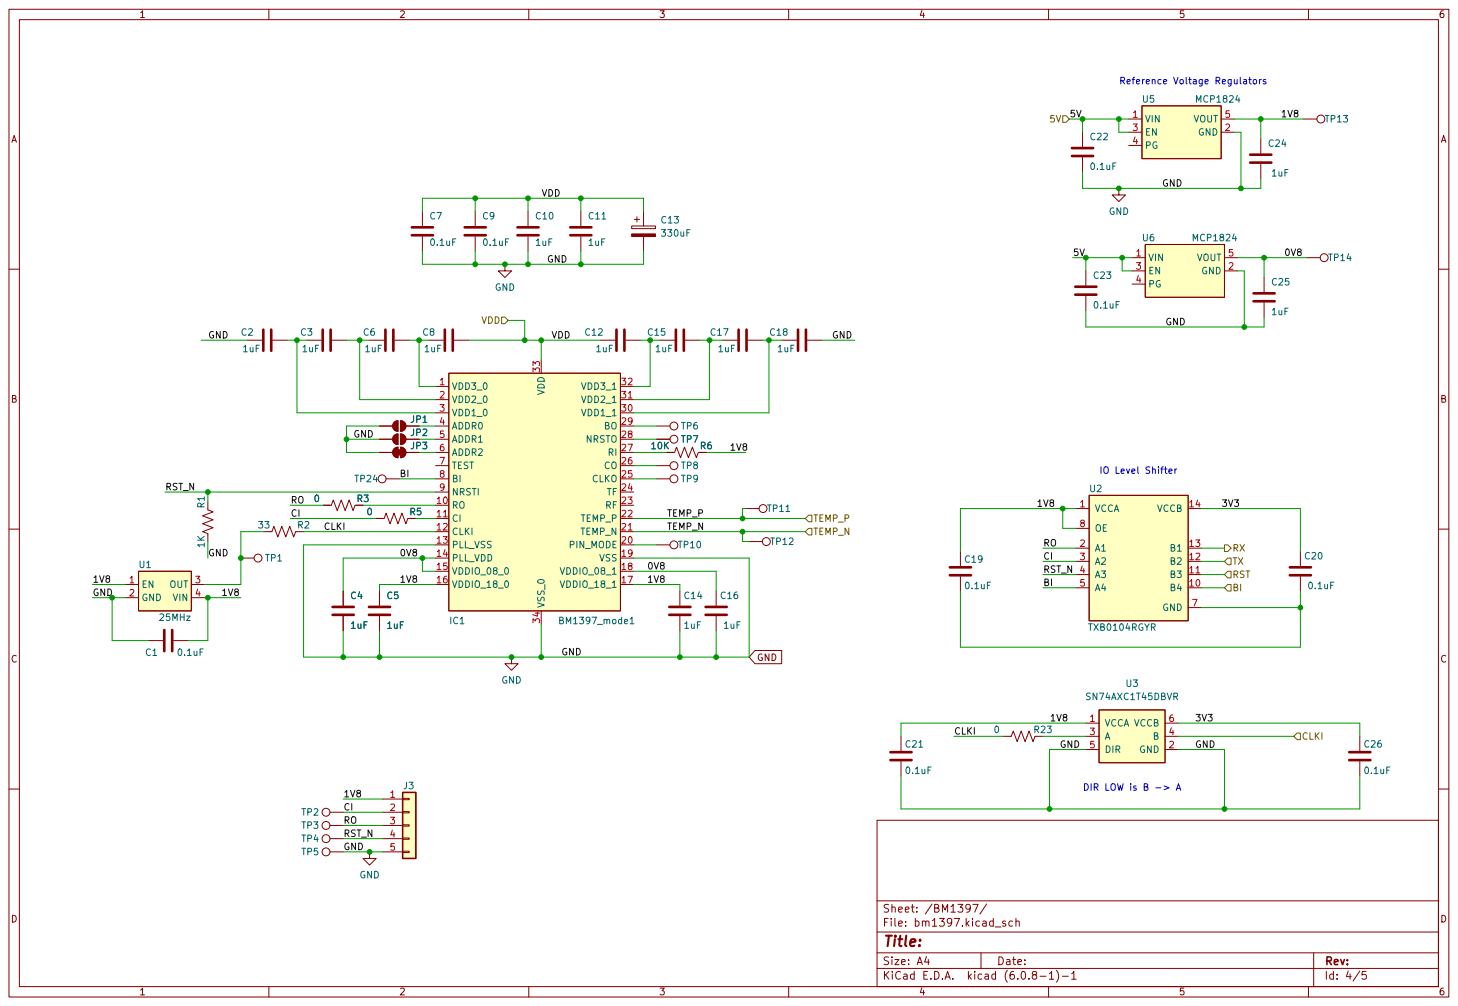
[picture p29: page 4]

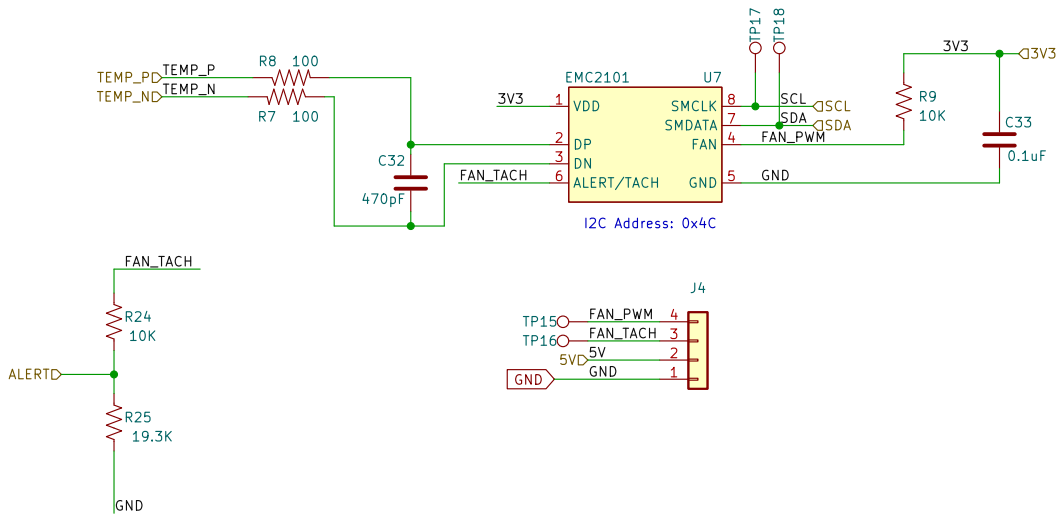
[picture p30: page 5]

File: fan.kicad_sch Sheet: /Fan/
Id: 5/5 Title:

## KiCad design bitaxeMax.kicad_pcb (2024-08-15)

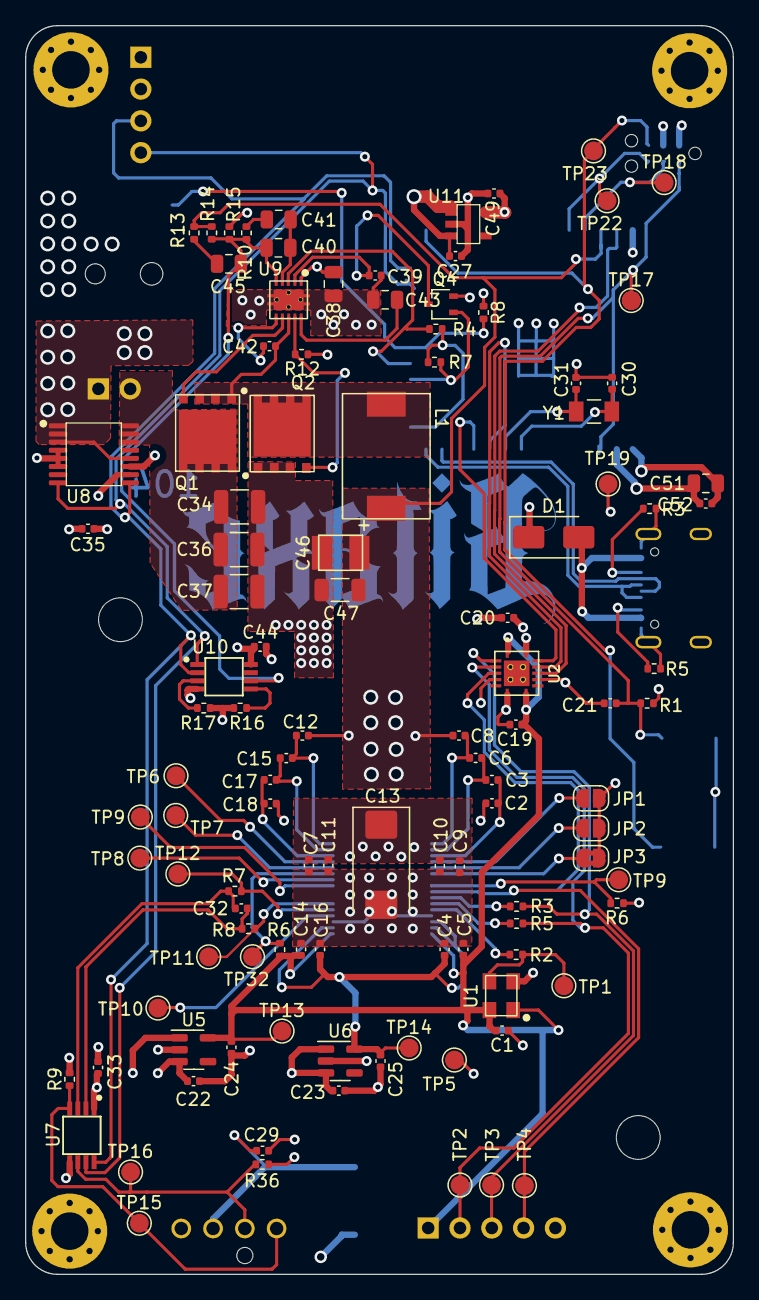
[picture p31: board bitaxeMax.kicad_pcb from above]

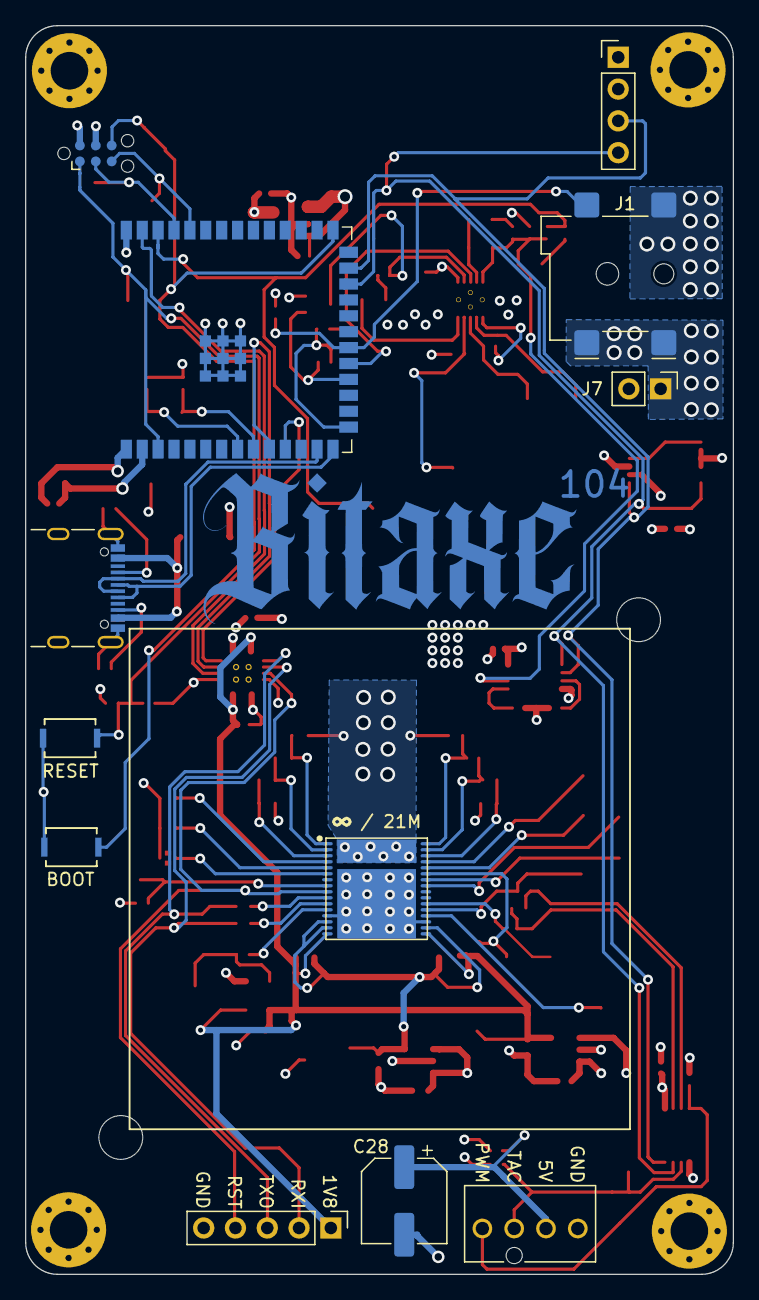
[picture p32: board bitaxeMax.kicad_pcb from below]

Board: 4 copper layers, 56.5 x 99.8 mm, 129 parts (12 on the bottom side), 68 nets.

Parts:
C1, C7, C9, C19, C20, C22, C23, C29, C33, C42, C52: 0.1uF; C_0402_1005Metric
C2, C3, C4, C5, C6, C8, C10, C11, C12, C14, C15, C16, C17, C18, C21, C24, C25, C27, C35, C44, C49: 1uF; C_0402_1005Metric
C13: 330uF; CP_EIA-7343-31_Kemet-D_Pad2.25x2.55mm_HandSolder
C28: 220uF; CP_Elec_6.3x7.7
C30, C31: 6.8pF; C_0402_1005Metric
C32: 470pF; C_0402_1005Metric
C34, C36, C37: 47uF; C_1210_3225Metric
C38: 1uF; C_0805_2012Metric
C39: 3.3nF; C_0402_1005Metric
C40: 180pF; C_0805_2012Metric
C41: 1.5nF; C_0805_2012Metric
C43, C51: 10uF; C_0805_2012Metric
C45: 470pF; C_0805_2012Metric
C46: 220uF; CAP_2R5TPE220MAFB
C47: 100uF; C_1206_3216Metric
D1: SS310; D_SMA
H1, H2, H3, H4: AlignmentHole; MountingHole_3mm_Pad_Via
H5, H6: MountingHole; MountingHole_3.5mm
IC1: BM1397_mode1; BM1397
J1: 54-00164; BarrelJack_Wuerth_694106106102_2.0x5.5mm
J3: Conn_01x05; PinHeader_1x05_P2.54mm_Vertical
J4: Conn_01x04; 470531000
J5: TC2030-IDC; Tag-Connect_TC2030-IDC-NL_2x03_P1.27mm_Vertical
J7: Conn_01x02; PinHeader_1x02_P2.54mm_Vertical
J8: USB_C_Receptacle_USB2.0; USB_C_Receptacle_GCT_USB4105-xx-A_16P_TopMnt_Horizontal
J9: Conn_01x04; PinHeader_1x04_P2.54mm_Vertical
JP1, JP2: SolderJumper_2_Open; SolderJumper-2_P1.3mm_Open_RoundedPad1.0x1.5mm
JP3: SolderJumper_2_Bridged; SolderJumper-2_P1.3mm_Bridged2Bar_RoundedPad1.0x1.5mm
L1: 150nH; FP1005R1-R15-R
Q1, Q2: CSD17311Q5
Q4: 2N7002K; SOT-323_SC-70
R1, R4, R6, R6#2, R7, R9, R36: 10k; R_0402_1005Metric
R2, R3, R5#2: 0; R_0402_1005Metric
R3#2, R5: 5.1k; R_0402_1005Metric
R7#2, R8#2: 100; R_0402_1005Metric
R8: 1M; R_0402_1005Metric
R10: 3.83k; R_0402_1005Metric
R12: 4.12k; R_0402_1005Metric
R13: 1.33k; R_0402_1005Metric
R14: 4.99k; R_0402_1005Metric
R15: 3.32k; R_0402_1005Metric
R16: 80k; R_0402_1005Metric
R17: DNP; R_0402_1005Metric
SW1, SW2: GT-TC029B-H025-L1N; SW_CS1213AGF260_CRS
TP1, TP2, TP3, TP4, TP5, TP6, TP7, TP8, TP9, TP9#2, TP10, TP11, TP12, TP13, TP14, TP15, TP16, TP17, TP18, TP19, TP22, TP23, TP32: TestPoint; TestPoint_Pad_D1.5mm
U1: 25MHz; O 25,0-JO32-B-1V3-1-T1-LF
U2: TXB0104RGYR; TXB0104
U5, U6: MCP1824; SOT-23-5
U7: EMC2101; TSSOP-8_3x3mm_P0.65mm
U8: INA260; TSSOP-16_4.4x5mm_P0.65mm
U9: TPS40305
U10: DS4432U+; TSSOP-8_3x3mm_P0.65mm
U11: RT9080-33GJ5
U12: ESP32-S3-WROOM-1
Y1: 32.768kHz; SC32S-7PF20PPM

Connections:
/3V3: C20.1, C33.1, C35.1, C44.1, C49.1, C51.1, C52.1, J5.2, J9.2, R1.1, R4.1, R7.1, R8.1, R9.2, R36.2, TP19.1, U2.14 (VCCB), U7.1 (VDD), U8.10 (VS), U10.8 (VCC), U11.5 (VOUT), U12.2 (3V3), U12.15 (GPIO3/TOUCH3/ADC1_CH2*)
/5V: C22.1, C23.1, C27.1, C28.1, C29.1, C34.1, C36.1, C37.1, C38.1, D1.1, J4.2, J7.2, Q1.5 (D), U5.1 (VIN), U5.3 (EN), U6.1 (VIN), U6.3 (EN), U8.14 (IN-), U8.15 (IN-), U8.16 (IN-), U9.1 (VDD), U11.1 (VIN), U11.3 (EN)
/BM1397/0V8: C4.1, C16.1, C25.1, IC1.14 (PLL_VDD), IC1.15 (VDDIO_08_0), IC1.18 (VDDIO_08_1), TP14.1, U6.5 (VOUT)
/BM1397/1V8: C1.2, C5.1, C14.1, C19.1, C24.1, IC1.16 (VDDIO_18_0), IC1.17 (VDDIO_18_1), J3.1, R6#2.2, TP13.1, U1.1 (EN), U1.4 (VIN), U2.1 (VCCA), U2.8 (OE), U5.5 (VOUT)
/BM1397/BM_BI: IC1.8 (BI), R6.2, TP9.1
/BM1397/BM_CLKI: IC1.12 (CLKI), R2.2
/BM1397/CI: J3.2, R5#2.1, TP2.1, U2.3 (A2)
/BM1397/RO: J3.3, R3.1, TP3.1, U2.2 (A1)
/BM1397/RST_N: IC1.9 (NRSTI), J3.4, TP4.1, U2.4 (A3)
/ESP32/EN: C21.1, J5.1, R1.2, SW1.2, TP17.1, U12.3 (EN)
/ESP32/IO0: J5.6, SW2.2, TP23.1, U12.27 (GPIO0/BOOT*)
/ESP32/P_RX: J5.5, TP22.1, U12.36 (U0RXD/GPIO44/CLK_OUT2)
/ESP32/P_TX: J5.3, TP18.1, U12.37 (U0TXD/GPIO43/CLK_OUT1)
/ESP32/XIN32: C30.1, U12.8 (GPIO15/U0RTS/ADC2_CH4/XTAL_32K_P), Y1.1
/ESP32/XOUT32: C31.1, U12.9 (GPIO16/U0CTS/ADC2_CH5/XTAL_32K_NH5), Y1.2
/Fan/FAN_PWM: J4.4, R9.1, TP15.1, U7.4 (FAN)
/Fan/FAN_TACH: J4.3, R36.1, TP16.1, U7.6 (ALERT/TACH)
/Power/OUT0: C40.2, C45.2, R10.2, R14.2, R15.1, U9.5 (FB), U10.6 (OUT0)
/Power/PGOOD: R4.2, U9.3 (PGOOD), U12.19 (GPIO11/TOUCH11/ADC2_CH0/FSPID/FSPIIO5/S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)
/Power/SW: C42.2, L1.1, Q1.1, Q1.2, Q1.3 (S), Q2.5 (D), U9.8 (SW)
/Power/VIN: J1.1, J7.1, U8.1 (IN+), U8.2 (IN+), U8.3 (IN+), U8.12 (VBUS)
/RST: U2.11 (B3), U12.39 (GPIO1/TOUCH1/ADC1_CH0)
/RX: U2.13 (B1), U12.11 (GPIO18/U1RXD/ADC2_CH7/CLK_OUT3)
/SCL: J9.3, U7.8 (SMCLK), U8.9 (SCL), U10.2 (SCL), U12.25 (GPIO48/SPICLK_N/SUBSPICLK_N_DIFF)
/SDA: J9.4, U7.7 (SMDATA), U8.8 (SDA), U10.1 (SDA), U12.24 (GPIO47/SPICLK_P/SUBSPICLK_P_DIFF)
/TEMP_N: IC1.21 (TEMP_N), R7#2.2, TP12.1
/TEMP_P: IC1.22 (TEMP_P), R8#2.1, TP11.1
/TX: U2.12 (B2), U12.10 (GPIO17/U1TXD/ADC2_CH6)
/VDD: C7.1, C8.2, C9.1, C10.1, C11.1, C12.1, C13.1, C46.1, C47.1, IC1.33 (VDD), L1.2, R13.1, R14.1, U12.38 (GPIO2/TOUCH2/ADC1_CH1)
GND: C1.1, C2.1, C4.2, C5.2, C7.2, C9.2, C10.2, C11.2, C13.2, C14.2, C16.2, C18.2, C19.2, C20.2, C21.2, C22.2, C23.2, C24.2, C25.2, C27.2, C28.2, C29.2, C30.2, C31.2, C33.2, C34.2, C35.2, C36.2, C37.2, C38.2, C39.2, C43.2, C44.2, C46.2, C47.2, C49.2, C51.2, C52.2, IC1.13 (PLL_VSS), IC1.19 (VSS), IC1.34 (VSS_0), J1.2, J3.5, J4.1, J5.4, J8.A1 (GND), J8.A12 (GND), J8.B1 (GND), J8.B12 (GND), J8.S1 (SHIELD), J9.1, JP1.1 (A), JP2.1 (A), JP3.1 (A), Q2.1, Q2.2, Q2.3 (S), Q4.2 (S), R3#2.1, R5.1, R6.1, R12.2, R15.2, R16.2, R17.2, SW1.1, SW2.1, TP5.1, U1.2 (GND), U2.5 (A4), U2.7 (GND), U2.10 (B4), U2.15 (GND), U2.16 (GND), U2.17 (GND), U2.18 (GND), U2.19 (GND), U5.2 (GND), U6.2 (GND), U7.5 (GND), U8.4 (A1), U8.5 (A0), U8.6 (GND), U8.11 (GND), U9.11 (GND), U10.4 (GND), U11.2 (GND), U12.1 (GND), U12.40 (GND), U12.41 (GND)
NET-(J8-CC1): J8.A5 (CC1), R3#2.2
unnamed: C2.2, C3.1, IC1.3 (VDD1_0)
unnamed: C3.2, C6.1, IC1.2 (VDD2_0)
unnamed: C6.2, C8.1, IC1.1 (VDD3_0)
unnamed: C12.2, C15.1, IC1.32 (VDD3_1)
unnamed: C15.2, C17.1, IC1.31 (VDD2_1)
unnamed: C17.2, C18.1, IC1.30 (VDD1_1)
unnamed: C32.1, R8#2.2, U7.2 (DP)
unnamed: C32.2, R7#2.1, U7.3 (DN)
unnamed: C40.1, C41.1, U9.4 (COMP)
unnamed: C41.2, R10.1
unnamed: C42.1, U9.6 (BOOT)
unnamed: C43.1, U9.10 (BP)
unnamed: C45.1, R13.2
unnamed: D1.2, J8.A4 (VBUS), J8.A9 (VBUS), J8.B4 (VBUS), J8.B9 (VBUS)
unnamed: IC1.4 (ADDR0), JP1.2 (B)
unnamed: IC1.5 (ADDR1), JP2.2 (B)
unnamed: IC1.6 (ADDR2), JP3.2 (B)
unnamed: IC1.10 (RO), R3.2
unnamed: IC1.11 (CI), R5#2.2
unnamed: IC1.20 (PIN_MODE), TP10.1
unnamed: IC1.25 (CLKO), TP9#2.1
unnamed: IC1.26 (CO), TP8.1
unnamed: IC1.27 (RI), R6#2.1, TP32.1
unnamed: IC1.28 (NRSTO), TP7.1
unnamed: IC1.29 (BO), TP6.1
unnamed: J8.B5 (CC2), R5.2
unnamed: Q1.4 (G), U9.7 (HDRV)
unnamed: Q2.4 (G), R12.1, U9.9 (LDRV)
unnamed: C39.1, Q4.3 (D), U9.2 (SS)
unnamed: R2.1, TP1.1, U1.3 (OUT)
unnamed: R16.1, U10.5 (FS0)
unnamed: R17.1, U10.3 (FS1)
unnamed: J8.A7 (D-), J8.B7 (D-), U12.13 (GPIO19/U1RTS/ADC2_CH8/CLK_OUT2/USB_D-)
unnamed: J8.A6 (D+), J8.B6 (D+), U12.14 (GPIO20/U1CTS/ADC2_CH9/CLK_OUT1/USB_D+)
PLUG_SENSE: J1.3, R8.2, U12.20 (GPIO12/TOUCH12/ADC2_CH1/FSPICLK/FSPIIO6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)
PWR_EN: Q4.1 (G), R7.2, U12.18 (GPIO10/TOUCH10/ADC1_CH9/FSPICS0/FSPIIO4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)
x: U2.6, U2.9, U11.4

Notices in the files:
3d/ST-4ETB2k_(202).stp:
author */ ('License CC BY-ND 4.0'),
